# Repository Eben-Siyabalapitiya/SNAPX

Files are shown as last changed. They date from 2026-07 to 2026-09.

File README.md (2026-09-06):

# SNAPX

SNAPX is a small handheld camera I built on an ESP32-CAM. It has a live preview on
a 1.8 inch screen, a real metal shutter button on the side, and a 3D printed case I
designed in Onshape. When you press the button it takes a photo and saves it to the
ESP32's own flash memory. There is no SD card. To get the photos off it, the camera
makes its own WiFi network and hosts a small web gallery, so you connect your phone
to it, open a page in the browser, and you can view, download or delete every photo
on the device.

I made it because I wanted to build a camera from the sensor up instead of buying
one, and the ESP32-CAM is cheap and already has most of what you need on it.
Getting a live preview that was actually fast enough to use, and working around the
fact that there were no pins left for an SD card, were the two hard parts. Both are
written up further down.

The full writeup, more photos and Info with some more demo videos are on my site:
https://ebensiyabalapitiya.site/projects/snapx

## The build

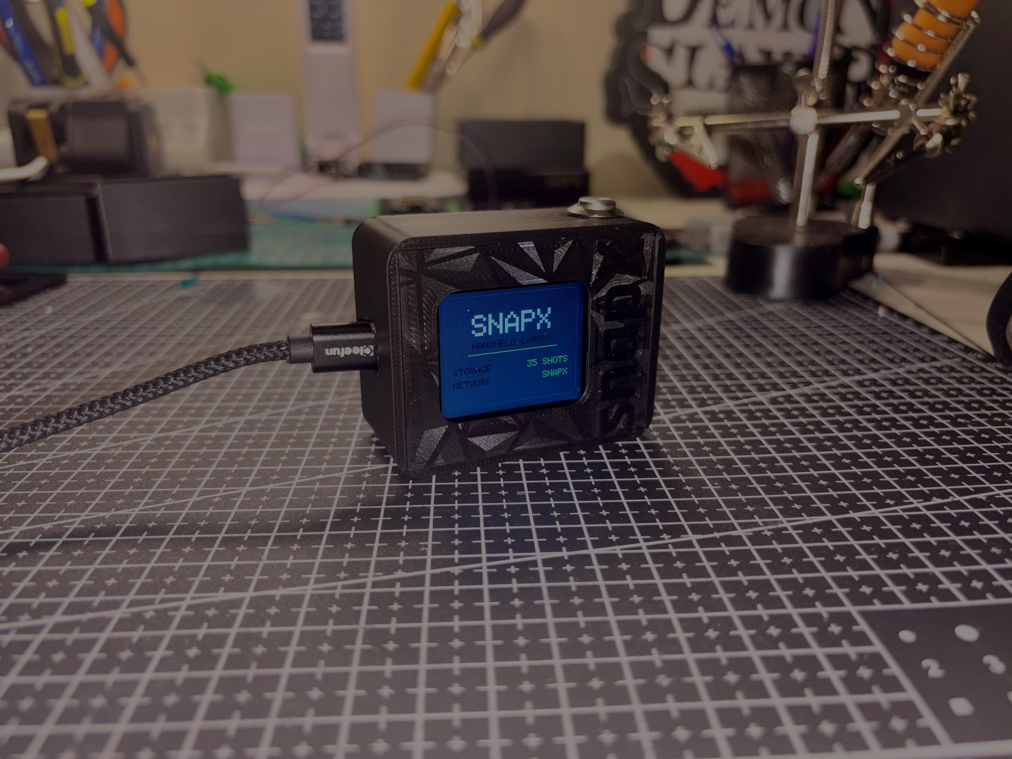
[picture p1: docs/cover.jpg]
SNAPX handheld camera


## What is in this repo

There is no custom PCB. SNAPX is off-the-shelf modules wired together by hand,
so the wiring diagram below is the whole electrical side of it.

| Folder | What is in it |
|---|---|
| `Firmware/` | The firmware. One Arduino sketch at `Firmware/SnapX/SnapX.ino` |
| `CAD/` | STL files for printing, and STEP files for editing the design |
| `docs/` | The build photo and the wiring diagram |
| `BOM.csv` | Every part you need |

## Parts

The full list with notes is in [BOM.csv](BOM.csv). The short version:

| Part | Notes |
|---|---|
| AI-Thinker ESP32-CAM | Classic board with the OV2640 sensor |
| ESP32-CAM-MB programmer board | Plugs onto the ESP32-CAM, makes flashing easy |
| 1.8 inch ST7735S SPI TFT | 128x160. The SD slot on it is not used |
| 12mm metal push button | Momentary, prewired |
| 18650 power bank enclosure and one 18650 cell | 5V USB out, sits outside the case |
| Onboard white LED on GPIO4 | Already on the board, used as the flash |
| Jumper wire and solder | For the screen and the button |

## Wiring

SNAPX wiring diagram

Screen to board:

| Screen pin | ESP32-CAM |
|---|---|
| VCC | 3.3V |
| GND | GND |
| CS | GPIO13 |
| DC (A0) | GPIO12 |
| MOSI (SDA) | GPIO15 |
| SCK | GPIO14 |
| LED | 3.3V |
| RESET | Not wired. `TFT_RST` is set to -1 in the firmware |

Button:

| Button | Goes to |
|---|---|
| One leg | GPIO3 |
| Other leg | GND |

No resistor needed. The firmware uses the internal pull-up and debounces the
button in software.

The flash is the white LED already on the board, on GPIO4.

The camera sensor uses the standard AI-Thinker pin map. The firmware handles it,
but it is the reason almost every pin is taken:

```
PWDN 32  RESET -1  XCLK 0  SIOD 26  SIOC 27
Y9 35  Y8 34  Y7 39  Y6 36  Y5 21  Y4 19  Y3 18  Y2 5
VSYNC 25  HREF 23  PCLK 22
```

This is what it looks like wired up on the bench, before any of it goes in the
case. Screen running off the board, jumpers to the ESP32-CAM-MB, power in over
USB.

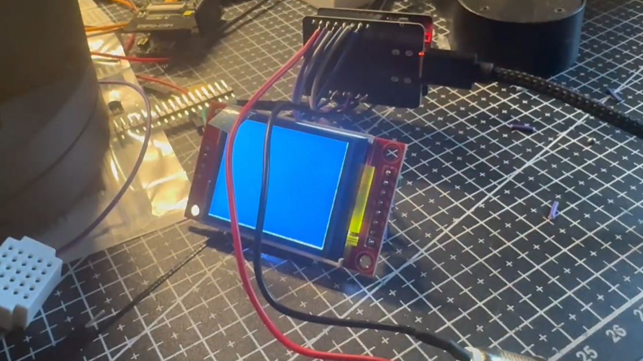
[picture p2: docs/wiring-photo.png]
SNAPX wired up on the bench


## Flashing

Open `Firmware/SnapX/SnapX.ino` in the Arduino IDE.

Board settings:

| Setting | Value |
|---|---|
| Board | AI Thinker ESP32-CAM |
| PSRAM | Enabled |
| Partition Scheme | Huge APP (3MB No OTA / 1MB SPIFFS) |

Install these two libraries from the Library Manager:

- Adafruit GFX Library
- Adafruit ST7735 and ST7789 Library

`esp_camera`, `LittleFS`, `WiFi` and `WebServer` already come with the ESP32 board
package, so there is nothing else to add.

The WiFi name and password are at the top of the sketch in a block marked
`USER CONFIG`. Change them if you want:

```c
#define AP_SSID     "SNAPX"
#define AP_PASSWORD "snapx1523"
```

The password has to be 8 to 63 characters or WPA2 will not take it. Set it to `""`
for an open network.

Two things that got me while building this:

1. The classic ESP32-CAM has no USB port and no auto reset. The ESP32-CAM-MB board
   handles that for you. If you flash without it, you have to connect GPIO0 to GND
   before you reset the board, start the upload, then take GPIO0 off GND so it
   boots your code instead of the bootloader.
2. Pick "AI Thinker ESP32-CAM" as the board, not "ESP32 Dev Module". The generic
   profile leaves PSRAM turned off, and then the camera will not start. It fails
   with a frame buffer malloc error. The camera needs PSRAM for its buffers.

## Using it

1. Plug in the power bank. You get a splash screen and then a short readout saying
   storage, network and sensor are up.
2. Point it and press the button. The LED fires, the screen goes white for a
   moment and freezes on the shot, then it saves.
3. To get the photos, connect your phone or laptop to the WiFi network `SNAPX`
   with the password `snapx1523`, then open `http://192.168.4.1/` in a browser.

The gallery shows every photo in a grid. Click one to see it full size with next
and previous and a download button. There is a small delete button on each photo.

## How it works

The preview never touches JPEG. The camera is set to RGB565 at QVGA, which is
already the format the screen wants, so each frame goes straight from the camera to
the display with no decoding step in between. The rotate and resize from the
320x240 camera frame down to the 160x128 screen is done with lookup tables that get
built once on the first frame, instead of being worked out for every pixel every
time. Before I did that the preview ran at about 0.1 fps. After it, it is actually
usable.

JPEG only happens when you press the shutter. The frame gets encoded with
`frame2jpg` at quality 95 and written to LittleFS under `/photos` as `img_00001.jpg`,
`img_00002.jpg` and so on. On startup the firmware reads that folder to find the
highest number, so the count keeps going after you unplug it.

The OV2640 has white balance, gain, exposure and lens correction switched off by
default. Turning them on made a big difference to how the photos look. Lens
correction is the one that fixes the dark corners.

## Why there is no SD card

This is the part that confuses people, so it is worth explaining. The camera sensor
uses almost every usable pin on the ESP32-CAM. The few that are left are the serial
lines the USB programmer needs, and one of those is where the shutter button is.
There were no pins left for SD card chip select and MISO. So photos go to the
internal flash instead, and the WiFi gallery is there to solve the problem that
created, which is getting the files back off the camera without pulling a card out.

## Case

The files are in [CAD/](CAD/), with a README in that folder that covers print
settings. Print `Case.stl` and `Cover.stl` once each, PLA or PETG, 0.2 mm layers,
3 walls, 15 to 20 percent infill, no supports. `SNAPX-enclosure.step` is the full
assembly if you want to change the design in another CAD program, and there are
per part STEP files next to it. The battery is a USB power bank that stays
outside, so the case only has to hold the board, the screen and the button.

## Known issues

- Saved photos come out rotated 90 degrees from what you saw in the preview. The
  preview is rotated in software and the encoder is handed the raw frame, so the
  two do not match. This is on my list to fix.
- The preview is only as fast as the screen can be written over SPI. It is fine for
  lining up a shot. It is not smooth video.
- The brownout detector is turned off at startup. If you power the camera from
  something that dips under load, you get glitches that look like screen bugs but
  are really the power dropping.
- The gallery only lists the first 200 photos. Anything past that is still saved
  and still downloads if you type the URL, it just does not show in the grid.
- The gallery has no password of its own. Anyone on the `SNAPX` WiFi can view and
  delete the photos. The WiFi password is the only thing in the way.
- You cannot look back at photos on the camera screen yet, only in the web gallery.

## License

MIT, see [LICENSE](LICENSE). Copyright Eben Siyabalapitiya.

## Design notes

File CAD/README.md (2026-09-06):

# CAD

The case was designed in Onshape. It holds the ESP32-CAM board, the 1.8 inch TFT
screen, and the shutter button. The battery does not go inside. Power is a USB
power bank that plugs into the board from outside the case.

## Files

| File | What it is | Print it |
|---|---|---|
| `Case.stl` | The main body of the enclosure. Roughly 66 x 53 x 30 mm. Has the screen window, the lens hole, the button hole, and the slot for the USB cable. | Yes, 1x |
| `Cover.stl` | The faceted front panel that closes the case. About 3.8 mm thick. | Yes, 1x |
| `SNAPX-enclosure.step` | The full assembly in STEP format, both parts together. Open this if you want the whole thing in another CAD program. | No |
| `Case.step` | Just the main body in STEP format. | No |
| `Cover.step` | Just the front panel in STEP format. | No |

## Printing

- Material: PLA or PETG, either is fine.
- Layer height: 0.2 mm.
- Walls: 3 perimeters.
- Infill: 15 to 20 percent.
- Supports: none needed. Print `Case.stl` with the open face down and the screen
  window facing up, and print `Cover.stl` flat.

Do a test fit with the board and screen before you glue or screw anything
together. The screen sits behind the window in the body, the button threads
through the hole in the side, and the USB port on the board should line up with
the cable slot.

## Exporting from Onshape again

STEP, one file per part:

1. Right click a part in the Parts list.
2. Export.
3. Format STEP. Save as `Case.step` or `Cover.step`.

STL, one file per part:

1. Right click a part in the Parts list.
2. Export.
3. Format STL, Binary, units mm. Save as `Case.stl` or `Cover.stl`.

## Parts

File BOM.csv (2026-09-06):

Part | Description | Quantity | Notes
AI-Thinker ESP32-CAM | Classic ESP32-CAM board with the OV2640 2MP sensor | 1 | The board the whole project runs on
ESP32-CAM-MB programmer board | Type-C USB to serial adapter with the CH340G chip that the ESP32-CAM plugs into | 1 | Used for flashing and for power. You can flash without it but it is a lot easier with it
1.8 inch ST7735S SPI TFT display | 128x160 colour LCD with a 4-wire SPI interface | 1 | The module has its own microSD slot but it is not used in this build
12mm momentary push button | Metal waterproof push button with pre-soldered wires and one normally-open contact | 1 | The shutter button on the side of the case
18650 power bank enclosure | Type-C power bank shell that takes one 18650 cell and outputs 5V over USB | 1 | Holds the battery. It sits outside the case and plugs into the board with a USB cable
18650 lithium cell | Single 3.7V 18650 rechargeable cell | 1 | Goes in the power bank shell
Onboard white LED | The white LED already fitted to the ESP32-CAM on GPIO4 | 0 | Already on the board so there is nothing to buy. Used as the flash
Jumper wire | Thin hookup wire for the screen and button connections | 1 | A small amount
Solder | Standard electronics solder | 1 | For the screen and button joints
3D printed case | Printed from Case.stl and Cover.stl in the CAD folder | 1 | PLA or PETG

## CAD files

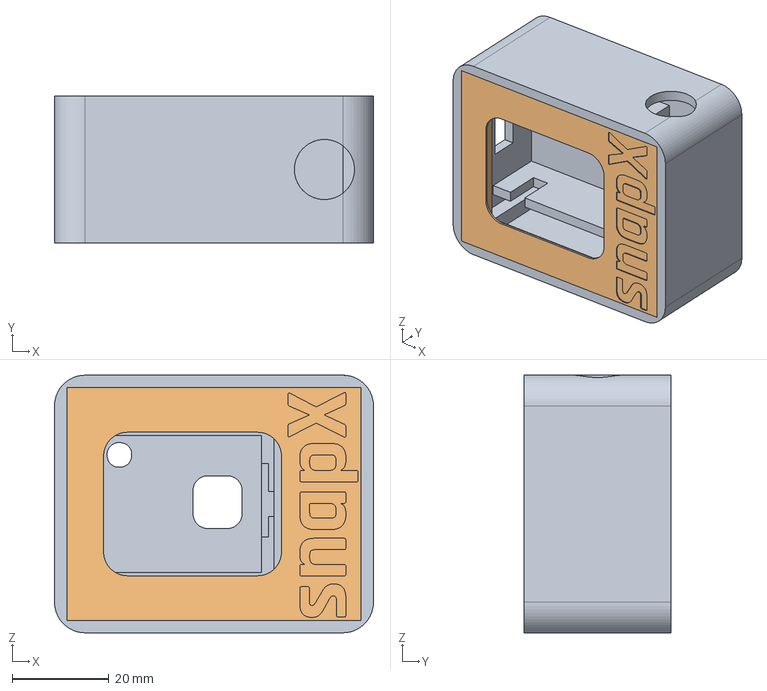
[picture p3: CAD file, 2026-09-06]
CAD/SNAPX-enclosure.step
66.0 x 30.5 x 53.3 mm

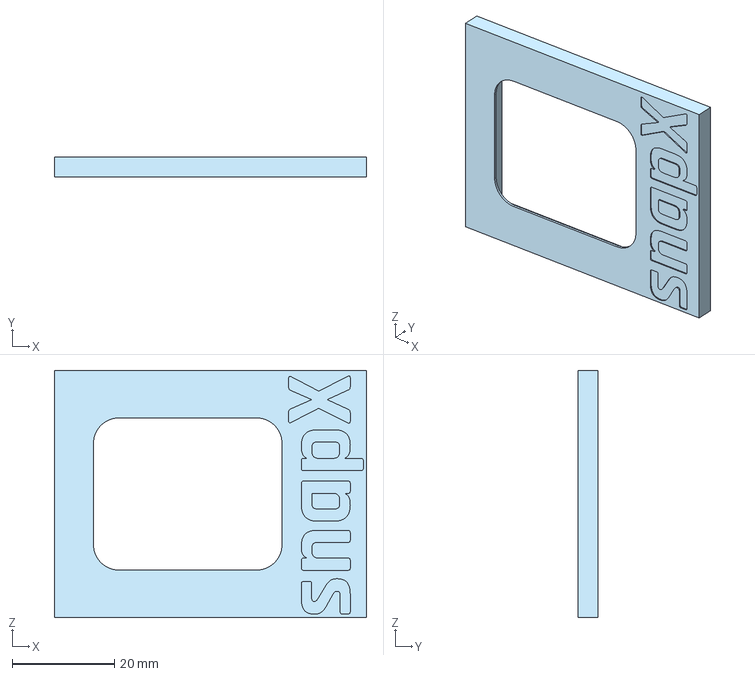
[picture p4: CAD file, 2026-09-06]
CAD/Cover.step
61.0 x 3.81 x 48.3 mm

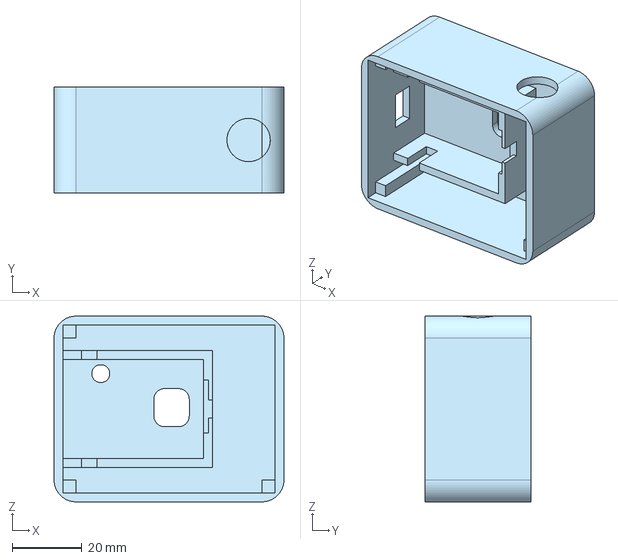
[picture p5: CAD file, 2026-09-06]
CAD/Case.step
66.0 x 30.5 x 53.3 mm

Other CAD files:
CAD/Case.stl
CAD/Cover.stl

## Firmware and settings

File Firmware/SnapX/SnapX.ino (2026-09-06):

#include "esp_camera.h"
#include "soc/soc.h"
#include "soc/rtc_cntl_reg.h"
#include "img_converters.h"
#include <Adafruit_GFX.h>
#include <Adafruit_ST7735.h>
#include <SPI.h>
#include "LittleFS.h"
#include <WiFi.h>
#include <WebServer.h>

// ===========================================================================
//  USER CONFIG  -  change these before flashing
// ===========================================================================
//  The camera hosts its own WiFi access point that serves the photo gallery.
//  Connect a phone or laptop to this network, then open http://192.168.4.1/
//  AP_PASSWORD must be 8 to 63 characters for WPA2. Use "" for an open network.
#define AP_SSID     "SNAPX"
#define AP_PASSWORD "snapx1523"
// ===========================================================================

#define TFT_CS   13
#define TFT_RST  -1
#define TFT_DC   12
#define TFT_SCLK 14
#define TFT_MOSI 15

SPIClass tftSPI(HSPI);
Adafruit_ST7735 tft = Adafruit_ST7735(&tftSPI, TFT_CS, TFT_DC, TFT_RST);

#define SCREEN_ROTATION 3
#define SCREEN_W 160
#define SCREEN_H 128
#define FRAME_W  320
#define FRAME_H  240

#define C_BG     0x0000
#define C_WHITE  0xFFFF
#define C_ACCENT 0x4EF0
#define C_DIM    0x6B6F
#define C_RED    0xFB90
#define C_PANEL  0x18E3

#define PWDN_GPIO_NUM   32
#define RESET_GPIO_NUM  -1
#define XCLK_GPIO_NUM   0
#define SIOD_GPIO_NUM   26
#define SIOC_GPIO_NUM   27
#define Y9_GPIO_NUM     35
#define Y8_GPIO_NUM     34
#define Y7_GPIO_NUM     39
#define Y6_GPIO_NUM     36
#define Y5_GPIO_NUM     21
#define Y4_GPIO_NUM     19
#define Y3_GPIO_NUM     18
#define Y2_GPIO_NUM     5
#define VSYNC_GPIO_NUM  25
#define HREF_GPIO_NUM   23
#define PCLK_GPIO_NUM   22

#define BUTTON_PIN     3
#define FLASH_LED_PIN  4
#define FLASH_DUTY     15
#define DEBOUNCE_MS    50

#define PHOTO_DIR    "/photos"
#define JPEG_QUALITY 95

WebServer server(80);

bool debouncedState = HIGH;
bool lastRawState = HIGH;
unsigned long lastDebounceTime = 0;

int nextPhotoIndex = 1;
bool fsReady = false;

void startCamera();
void handleButton();
void capturePhoto();
void findNextPhotoIndex();
int  countPhotos();
String photoPath(int index);
void drawFrameToScreen(camera_fb_t *fb);
void splashScreen();
void bootLine(const char *label, const char *value, uint16_t color, int y);
void toast(const char *text, uint16_t accent);
void fullStatus(const char *title, const char *sub, uint16_t accent);
void startWebServer();
void handleRoot();
void handlePhotoFile();
void handleDeletePhoto();

void setup() {
  WRITE_PERI_REG(RTC_CNTL_BROWN_OUT_REG, 0);

  Serial.begin(115200);
  delay(300);

  pinMode(BUTTON_PIN, INPUT_PULLUP);
  ledcAttach(FLASH_LED_PIN, 5000, 8);
  ledcWrite(FLASH_LED_PIN, 0);

  tftSPI.begin(TFT_SCLK, -1, TFT_MOSI, -1);

  tft.initR(INITR_BLACKTAB);
  tft.setRotation(SCREEN_ROTATION);
  tft.setSPISpeed(27000000);
  tft.fillScreen(C_BG);

  splashScreen();

  if (!LittleFS.begin(true)) {
    Serial.println("LittleFS mount failed");
    bootLine("STORAGE", "FAIL", C_RED, 78);
  } else {
    fsReady = true;
    if (!LittleFS.exists(PHOTO_DIR)) {
      LittleFS.mkdir(PHOTO_DIR);
    }
    findNextPhotoIndex();
    char buf[16];
    snprintf(buf, sizeof(buf), "%d SHOTS", nextPhotoIndex - 1);
    bootLine("STORAGE", buf, C_ACCENT, 78);
  }
  delay(350);

  startWebServer();
  bootLine("NETWORK", AP_SSID, C_ACCENT, 92);
  delay(350);

  startCamera();
  bootLine("SENSOR", "OV2640", C_ACCENT, 106);
  delay(600);

  tft.fillScreen(C_BG);
  Serial.println("SNAPX ready");
}

void splashScreen() {
  tft.setRotation((SCREEN_ROTATION + 2) % 4);
  tft.fillScreen(C_BG);

  tft.drawRoundRect(6, 6, SCREEN_W - 12, SCREEN_H - 12, 8, C_PANEL);

  tft.setTextSize(3);
  tft.setTextColor(C_WHITE);
  int16_t x1, y1;
  uint16_t w, h;
  tft.getTextBounds("SNAPX", 0, 0, &x1, &y1, &w, &h);
  tft.setCursor((SCREEN_W - w) / 2, 26);
  tft.print("SNAPX");

  tft.setTextSize(1);
  tft.setTextColor(C_DIM);
  tft.getTextBounds("HANDHELD CAMERA", 0, 0, &x1, &y1, &w, &h);
  tft.setCursor((SCREEN_W - w) / 2, 54);
  tft.print("HANDHELD CAMERA");

  int barX = 30, barY = 66, barW = SCREEN_W - 60;
  tft.drawFastHLine(barX, barY, barW, C_PANEL);
  for (int i = 0; i <= barW; i += 4) {
    tft.drawFastHLine(barX, barY, i, C_ACCENT);
    delay(6);
  }

  tft.setRotation(SCREEN_ROTATION);
}

void bootLine(const char *label, const char *value, uint16_t color, int y) {
  tft.setRotation((SCREEN_ROTATION + 2) % 4);
  tft.fillRect(12, y, SCREEN_W - 24, 10, C_BG);
  tft.setTextSize(1);
  tft.setTextColor(C_DIM);
  tft.setCursor(14, y + 1);
  tft.print(label);

  int16_t x1, y1;
  uint16_t w, h;
  tft.getTextBounds(value, 0, 0, &x1, &y1, &w, &h);
  tft.setTextColor(color);
tft.setCursor(SCREEN_W - 16 - w, y + 1);
  tft.print(value);

  tft.setRotation(SCREEN_ROTATION);
}

void toast(const char *text, uint16_t accent) {
  tft.setRotation((SCREEN_ROTATION + 2) % 4);

  int boxH = 22;
  int boxY = SCREEN_H - boxH - 8;
  int boxX = 10;
  int boxW = SCREEN_W - 20;

  tft.fillRoundRect(boxX, boxY, boxW, boxH, 6, C_BG);
  tft.drawRoundRect(boxX, boxY, boxW, boxH, 6, accent);
  tft.fillRect(boxX + 4, boxY + 6, 3, boxH - 12, accent);

  tft.setTextSize(1);
  tft.setTextColor(C_WHITE);
  int16_t x1, y1;
  uint16_t w, h;
  tft.getTextBounds(text, 0, 0, &x1, &y1, &w, &h);
  tft.setCursor(boxX + (boxW - w) / 2, boxY + (boxH - h) / 2);
  tft.print(text);

  tft.setRotation(SCREEN_ROTATION);
}

void fullStatus(const char *title, const char *sub, uint16_t accent) {
  tft.setRotation((SCREEN_ROTATION + 2) % 4);

  tft.fillScreen(C_BG);
  tft.drawRoundRect(6, 6, SCREEN_W - 12, SCREEN_H - 12, 8, C_PANEL);

  int16_t x1, y1;
  uint16_t w, h;

  tft.setTextSize(2);
  tft.setTextColor(accent);
  tft.getTextBounds(title, 0, 0, &x1, &y1, &w, &h);
  tft.setCursor((SCREEN_W - w) / 2, SCREEN_H / 2 - 16);
  tft.print(title);

  tft.setTextSize(1);
  tft.setTextColor(C_DIM);
  tft.getTextBounds(sub, 0, 0, &x1, &y1, &w, &h);
  tft.setCursor((SCREEN_W - w) / 2, SCREEN_H / 2 + 8);
  tft.print(sub);

  tft.setRotation(SCREEN_ROTATION);
}

void startWebServer() {
  WiFi.softAP(AP_SSID, AP_PASSWORD);
  Serial.print("AP started, connect to WiFi \"");
  Serial.print(AP_SSID);
  Serial.println("\" then visit http://192.168.4.1/");

  server.on("/", handleRoot);
  server.on("/delete", handleDeletePhoto);
  server.onNotFound(handlePhotoFile);
  server.begin();
}

void handleRoot() {
  static String names[200];
  int count = 0;
  File dir = LittleFS.open(PHOTO_DIR);
  File entry = dir.openNextFile();
  while (entry && count < 200) {
    String name = String(entry.name());
    names[count++] = name.substring(name.lastIndexOf('/') + 1);
    entry = dir.openNextFile();
  }

  String js = "[";
  for (int i = count - 1; i >= 0; i--) {
    js += "\"" + names[i] + "\"";
    if (i > 0) js += ",";
  }
  js += "]";

  String html =
    "<!DOCTYPE html><html><head>"
    "<meta charset=\"utf-8\">"
    "<meta name=\"viewport\" content=\"width=device-width,initial-scale=1\">"
    "<title>SNAPX</title><style>"
    "*{box-sizing:border-box;margin:0;padding:0}"
    "body{background:#08080a;color:#f4f4f6;min-height:100vh;"
    "font-family:-apple-system,BlinkMacSystemFont,'Segoe UI',Inter,sans-serif;"
    "-webkit-font-smoothing:antialiased;padding-bottom:60px}"
    "body:before{content:'';position:fixed;inset:0;pointer-events:none;"
    "background:radial-gradient(900px 500px at 50% -10%,#1b2a24 0%,transparent 70%)}"
    "header{position:sticky;top:0;z-index:20;"
    "background:rgba(8,8,10,.82);backdrop-filter:blur(14px);"
    "border-bottom:1px solid #1a1a1f;padding:16px 20px;"
    "display:flex;align-items:center;gap:11px}"
    ".dot{width:7px;height:7px;border-radius:50%;background:#4ade80;"
    "box-shadow:0 0 10px #4ade80;animation:pulse 2.4s infinite}"
    "@keyframes pulse{0%,100%{opacity:1}50%{opacity:.35}}"
    ".logo{font-size:16px;font-weight:700;letter-spacing:.18em}"
    ".sub{font-size:11px;color:#5f5f6b;letter-spacing:.1em;"
    "border-left:1px solid #26262d;padding-left:11px}"
    ".count{margin-left:auto;font-size:12px;color:#7a7a86;"
    "background:#141418;border:1px solid #232329;border-radius:999px;"
    "padding:5px 11px;font-variant-numeric:tabular-nums}"
    "main{position:relative;padding:22px 20px;max-width:1200px;margin:0 auto}"
    ".grid{display:grid;gap:14px;"
    "grid-template-columns:repeat(auto-fill,minmax(158px,1fr))}"
    ".card{position:relative;border-radius:16px;overflow:hidden;cursor:pointer;"
    "background:#121216;border:1px solid #212128;"
    "transition:transform .2s cubic-bezier(.2,.8,.2,1),border-color .2s,box-shadow .2s}"
    ".card:hover{transform:translateY(-3px);border-color:#3a3a45;"
    "box-shadow:0 10px 30px rgba(0,0,0,.55)}"
    ".card img{width:100%;aspect-ratio:4/3;object-fit:cover;display:block;"
    "background:#1a1a20;transition:transform .35s ease}"
    ".card:hover img{transform:scale(1.05)}"
    ".meta{display:flex;justify-content:space-between;align-items:center;"
    "padding:9px 12px;font-size:11px;color:#84848f;letter-spacing:.06em;"
    "font-variant-numeric:tabular-nums;border-top:1px solid #1c1c22}"
    ".del{position:absolute;top:8px;right:8px;width:27px;height:27px;"
    "border-radius:9px;background:rgba(8,8,10,.7);backdrop-filter:blur(6px);"
    "color:#fb7185;display:flex;align-items:center;justify-content:center;"
    "font-size:16px;line-height:1;text-decoration:none;font-weight:600;"
    "opacity:0;transition:opacity .2s,background .2s,color .2s;z-index:2}"
    ".card:hover .del{opacity:1}"
    ".del:hover{background:#fb7185;color:#08080a}"
    "@media(hover:none){.del{opacity:1}}"
    ".empty{text-align:center;padding:90px 20px}"
    ".empty .ico{font-size:34px;opacity:.25;margin-bottom:14px}"
    ".empty .big{font-size:15px;color:#9a9aa4;margin-bottom:6px}"
    ".empty .txt{font-size:13px;color:#55555f}"
    "#lb{position:fixed;inset:0;z-index:50;display:none;"
    "background:rgba(4,4,6,.94);backdrop-filter:blur(8px);"
    "align-items:center;justify-content:center;flex-direction:column;gap:16px}"
    "#lb.on{display:flex}"
    "#lb img{max-width:92vw;max-height:74vh;border-radius:12px;"
    "box-shadow:0 24px 70px rgba(0,0,0,.7)}"
    ".lbbar{display:flex;align-items:center;gap:14px;font-size:12px;color:#8a8a95;"
    "font-variant-numeric:tabular-nums}"
    ".lbbtn{background:#16161b;border:1px solid #26262d;color:#e6e6ea;"
    "border-radius:9px;padding:8px 14px;font-size:13px;cursor:pointer;"
    "text-decoration:none;transition:background .18s,border-color .18s}"
    ".lbbtn:hover{background:#20202a;border-color:#3a3a45}"
    ".lbclose{position:absolute;top:18px;right:20px;font-size:26px;color:#6f6f7a;"
    "cursor:pointer;line-height:1}"
    ".lbclose:hover{color:#f4f4f6}"
    "</style></head><body>"
    "<header><span class=\"dot\"></span>"
    "<span class=\"logo\">SNAPX</span>"
    "<span class=\"sub\">GALLERY</span>"
    "<span class=\"count\">" + String(count) + " photo" +
    String(count == 1 ? "" : "s") + "</span></header><main>";

  if (count == 0) {
    html += "<div class=\"empty\"><div class=\"ico\">&#9673;</div>"
            "<div class=\"big\">No photos yet</div>"
            "<div class=\"txt\">Press the shutter button to take your first shot.</div></div>";
  } else {
    html += "<div class=\"grid\">";
    for (int i = count - 1; i >= 0; i--) {
      String url = "/photos/" + names[i];
      String label = names[i];
      label.replace("img_", "");
      label.replace(".jpg", "");
      int idx = count - 1 - i;
      html += "<div class=\"card\" onclick=\"openLb(" + String(idx) + ")\">"
              "<a class=\"del\" href=\"/delete?f=" + names[i] + "\" "
              "onclick=\"event.stopPropagation();return confirm('Delete this photo?')\">&times;</a>"
              "<img src=\"" + url + "\" loading=\"lazy\">"
              "<div class=\"meta\"><span>#" + label + "</span><span>JPG</span></div>"
              "</div>";
    }
    html += "</div>";
  }

  html +=
    "</main>"
    "<div id=\"lb\" onclick=\"if(event.target.id=='lb')closeLb()\">"
    "<span class=\"lbclose\" onclick=\"closeLb()\">&times;</span>"
    "<img id=\"lbimg\">"
    "<div class=\"lbbar\">"
    "<button class=\"lbbtn\" onclick=\"step(-1)\">&larr;</button>"
    "<span id=\"lbnum\"></span>"
    "<button class=\"lbbtn\" onclick=\"step(1)\">&rarr;</button>"
    "<a class=\"lbbtn\" id=\"lbdl\" download>Download</a>"
    "</div></div>"
    "<script>"
    "var P=" + js + ";var cur=0;"
    "function openLb(i){cur=i;render();document.getElementById('lb').classList.add('on');}"
    "function closeLb(){document.getElementById('lb').classList.remove('on');}"
    "function step(d){if(!P.length)return;cur=(cur+d+P.length)%P.length;render();}"
    "function render(){var u='/photos/'+P[cur];"
    "document.getElementById('lbimg').src=u;"
    "document.getElementById('lbdl').href=u;"
    "document.getElementById('lbnum').textContent=(cur+1)+' / '+P.length;}"
    "document.addEventListener('keydown',function(e){"
    "if(!document.getElementById('lb').classList.contains('on'))return;"
    "if(e.key=='Escape')closeLb();"
    "if(e.key=='ArrowLeft')step(-1);"
    "if(e.key=='ArrowRight')step(1);});"
    "</script></body></html>";

  server.send(200, "text/html", html);
}

void handleDeletePhoto() {
  if (server.hasArg("f")) {
    String name = server.arg("f");
    if (name.indexOf('/') == -1 && name.indexOf("..") == -1) {
      LittleFS.remove(String(PHOTO_DIR) + "/" + name);
    }
  }
  server.sendHeader("Location", "/");
  server.send(302, "text/plain", "");
}

void handlePhotoFile() {
  String path = server.uri();
  if (!LittleFS.exists(path)) {
    server.send(404, "text/plain", "Not found");
    return;
  }
  File f = LittleFS.open(path, FILE_READ);
  server.streamFile(f, "image/jpeg");
  f.close();
}

void startCamera() {
  camera_config_t config = {};
  config.ledc_channel = LEDC_CHANNEL_0;
  config.ledc_timer   = LEDC_TIMER_0;
  config.pin_d0 = Y2_GPIO_NUM;
  config.pin_d1 = Y3_GPIO_NUM;
  config.pin_d2 = Y4_GPIO_NUM;
  config.pin_d3 = Y5_GPIO_NUM;
  config.pin_d4 = Y6_GPIO_NUM;
  config.pin_d5 = Y7_GPIO_NUM;
  config.pin_d6 = Y8_GPIO_NUM;
  config.pin_d7 = Y9_GPIO_NUM;
  config.pin_xclk = XCLK_GPIO_NUM;
  config.pin_pclk = PCLK_GPIO_NUM;
  config.pin_vsync = VSYNC_GPIO_NUM;
  config.pin_href = HREF_GPIO_NUM;
  config.pin_sccb_sda = SIOD_GPIO_NUM;
  config.pin_sccb_scl = SIOC_GPIO_NUM;
  config.pin_pwdn = PWDN_GPIO_NUM;
  config.pin_reset = RESET_GPIO_NUM;
  config.xclk_freq_hz = 20000000;
  config.pixel_format = PIXFORMAT_RGB565;
  config.frame_size = FRAMESIZE_QVGA;
  config.fb_location = CAMERA_FB_IN_PSRAM;
  config.fb_count = 2;
  config.grab_mode = CAMERA_GRAB_LATEST;

  esp_err_t err = esp_camera_init(&config);
  if (err != ESP_OK) {
    Serial.printf("Camera init FAILED: 0x%x\n", err);
    fullStatus("SENSOR", "INIT FAILED", C_RED);
    while (true) delay(1000);
  }
}

#define FLIP_H false
#define FLIP_V false

void drawFrameToScreen(camera_fb_t *fb) {
  if (fb->width != FRAME_W || fb->height != FRAME_H) return;
  uint16_t *pixels = (uint16_t *)fb->buf;
  static uint16_t rowBuf[SCREEN_W];

  static int srcOffset[SCREEN_W];
  static int srcXMap[SCREEN_H];
  static bool mapsReady = false;
  if (!mapsReady) {
    for (int x = 0; x < SCREEN_W; x++) {
      int sy = (x * FRAME_H) / SCREEN_W;
      if (FLIP_H) sy = FRAME_H - 1 - sy;
      srcOffset[x] = sy * FRAME_W;
    }
    for (int y = 0; y < SCREEN_H; y++) {
      int sx = (y * FRAME_W) / SCREEN_H;
      if (!FLIP_V) sx = FRAME_W - 1 - sx;
      srcXMap[y] = sx;
    }
    mapsReady = true;
  }

  tft.startWrite();
  tft.setAddrWindow(0, 0, SCREEN_W, SCREEN_H);
  for (int y = 0; y < SCREEN_H; y++) {
    int srcX = srcXMap[y];
    for (int x = 0; x < SCREEN_W; x++) {
      rowBuf[x] = pixels[srcOffset[x] + srcX];
    }
    tft.writePixels(rowBuf, SCREEN_W, true, true);
  }
  tft.endWrite();
}

void loop() {
  handleButton();
  server.handleClient();

  camera_fb_t *fb = esp_camera_fb_get();
  if (!fb) return;

  drawFrameToScreen(fb);

  esp_camera_fb_return(fb);
}

void handleButton() {
  bool raw = digitalRead(BUTTON_PIN);

  if (raw != lastRawState) {
    lastDebounceTime = millis();
  }

  if ((millis() - lastDebounceTime) > DEBOUNCE_MS) {
    if (raw != debouncedState) {
      debouncedState = raw;
      if (debouncedState == LOW) {
        capturePhoto();
      }
    }
  }
  lastRawState = raw;
}

void capturePhoto() {
  ledcWrite(FLASH_LED_PIN, FLASH_DUTY);
  delay(120);

  camera_fb_t *stale = esp_camera_fb_get();
  if (stale) {
    esp_camera_fb_return(stale);
  }
  camera_fb_t *fb = esp_camera_fb_get();
  ledcWrite(FLASH_LED_PIN, 0);

  if (!fb) return;

  tft.fillScreen(C_WHITE);
  delay(45);
  drawFrameToScreen(fb);

  if (!fsReady) {
    toast("NO STORAGE", C_RED);
    delay(1200);
    esp_camera_fb_return(fb);
    return;
  }

  toast("SAVING", C_DIM);

  uint8_t *jpgBuf = NULL;
  size_t jpgLen = 0;
  bool ok = false;
  if (frame2jpg(fb, JPEG_QUALITY, &jpgBuf, &jpgLen)) {
    String path = photoPath(nextPhotoIndex);
    File f = LittleFS.open(path, FILE_WRITE);
    if (f) {
      f.write(jpgBuf, jpgLen);
      f.close();
      Serial.printf("Saved %s (%u bytes)\n", path.c_str(), (unsigned)jpgLen);
      nextPhotoIndex++;
      ok = true;
    } else {
      Serial.println("Failed to open file for writing (flash full?)");
    }
    free(jpgBuf);
  } else {
    Serial.println("JPEG encode failed");
  }

  esp_camera_fb_return(fb);

  if (ok) {
    char msg[24];
    snprintf(msg, sizeof(msg), "SAVED  #%05d", nextPhotoIndex - 1);
    toast(msg, C_ACCENT);
  } else {
    toast("SAVE FAILED", C_RED);
  }
  delay(1100);
}

String photoPath(int index) {
  char buf[32];
  snprintf(buf, sizeof(buf), "%s/img_%05d.jpg", PHOTO_DIR, index);
  return String(buf);
}

int countPhotos() {
  int n = 0;
  File dir = LittleFS.open(PHOTO_DIR);
  if (!dir) return 0;
  File entry = dir.openNextFile();
  while (entry) {
    n++;
    entry = dir.openNextFile();
  }
  return n;
}

void findNextPhotoIndex() {
  int maxIndex = 0;
  File dir = LittleFS.open(PHOTO_DIR);
  if (!dir) {
    nextPhotoIndex = 1;
    return;
  }

  File entry = dir.openNextFile();
  while (entry) {
    int idx = 0;
    const char *name = entry.name();
    const char *base = strrchr(name, '/');
    base = base ? base + 1 : name;
    if (sscanf(base, "img_%d.jpg", &idx) == 1 && idx > maxIndex) {
      maxIndex = idx;
    }
    entry = dir.openNextFile();
  }
  nextPhotoIndex = maxIndex + 1;
}

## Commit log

2026-07-21 Add brief description of SNAPX camera project
2026-07-24 Add screen test sketch for wiring debug
    Simple ST7735 test fills screen red and prints text used to confirm wiring separately from camera code.
2026-07-25 Integrate camera support and update TFT setup
    Added camera functionality and updated TFT display initialization.
2026-07-25 Refactor camera setup and image decoding
    Updated the image decoder configuration to not swap bytes.
    [SnapX.ino]
2026-07-25 Refactor camera setup and display handling
    Updated camera configuration and display settings.
2026-07-25 Refactor camera and TFT display handling
    Updated the TFT display handling and camera initialization process.
2026-07-25 Fix live preview corruption and switch to hardware SPI
    - Use real HSPI (remapped via GPIO matrix) instead of bit-banged SPI
    for the ST7735, since the camera pins never touch 12-15
    - Rotate to landscape and center the QQVGA frame so the address
    window never exceeds the panel's physical 128px width
    - Pass bigEndian=true to writePixels so the camera's already
    MSB-first RGB565 bytes aren't double byte-swapped
    [SnapX.ino]
2026-07-26 Add shutter button, flash, and WiFi photo gallery; switch storage to LittleFS
    - Button (GPIO3) takes a photo: flash pulse, freeze-frame confirmation,
    JPEG-encode, save
    - Photos saved to internal flash (LittleFS) instead of an SD card, since
    the SD-on-screen-module approach couldn't be gotten reliably stable on
    this board
    - Device hosts its own WiFi hotspot with a small gallery page (thumbnails,
    newest-first, tap to view full size) for retrieving photos wirelessly
    - Brownout detector disabled - camera+flash current draw was tripping it
    under the default settings
    [SnapX.ino]
2026-07-27 Refactor display settings and add delete photo feature
    Updated frame dimensions and added photo deletion functionality. Enhanced HTML structure for photo display.
2026-07-27 Rename CAMX to SNAPX and update quality settings
    [SnapX.ino]
2026-07-27 Write full README with hardware, wiring, flashing, and usage docs
    Adds a real cover photo and documents the actual current build in
    detail - parts list, wiring tables, flashing steps, how the storage
    and preview pipeline work, and known issues.
2026-07-27 Fix power bank output type and update WiFi password
    Updated power bank enclosure description and WiFi password in usage instructions.
2026-09-06 Add CAD folder and wiring diagram
2026-09-06 Reorganize folders, add STL and BOM files, update README
    [BOM.csv, Case.stl, Cover.stl]
2026-09-06 Remove PCB folder
2026-09-06 Add bench wiring photo to the README
2026-09-06 Add STEP files for the enclosure
    [Case.step, Cover.step]
2026-09-06 Add gitattributes to keep CAD files binary
2026-09-06 Add full assembly STEP file
    [SNAPX-enclosure.step]
